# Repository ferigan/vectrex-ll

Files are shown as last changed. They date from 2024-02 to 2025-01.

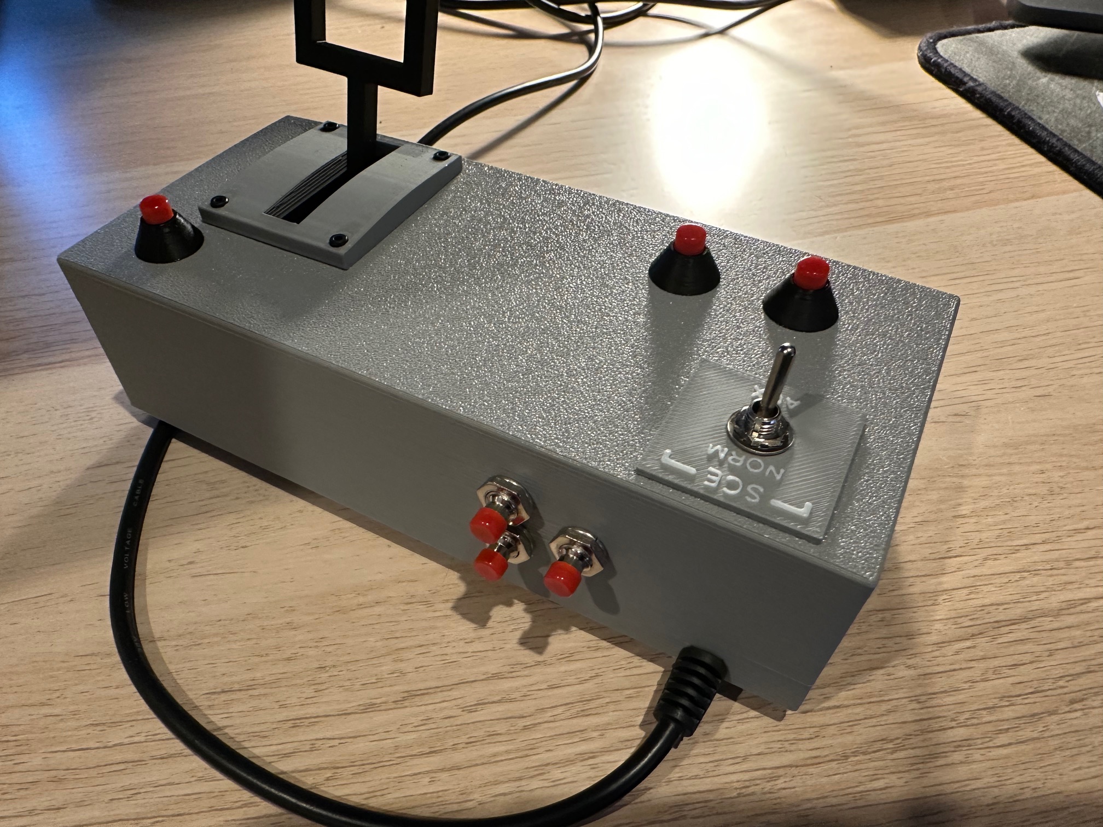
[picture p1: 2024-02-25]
Vectrex_LL_image2.jpg

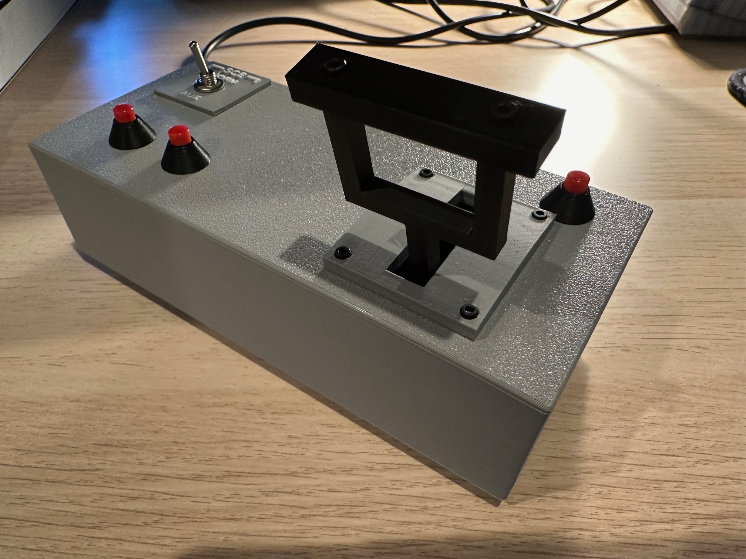
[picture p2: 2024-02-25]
Vectrex_LL_image1.jpg

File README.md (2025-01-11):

# vectrex-ll
Vectrex Lunar Lander controller
Vectrex_LL_image1

This project contains the designs and documentation for a prototype Vectrex Controller intended to be used for games such as Lunar Lander and Moon Lander

I have continued to develop the prototype into a final product, which can be built to order by emailing vectrex@retrocontrollers.com and requesting more information.

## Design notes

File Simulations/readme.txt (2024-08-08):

The simulation files provide here are designed to be used with https://www.falstad.com/circuit/circuitjs.html

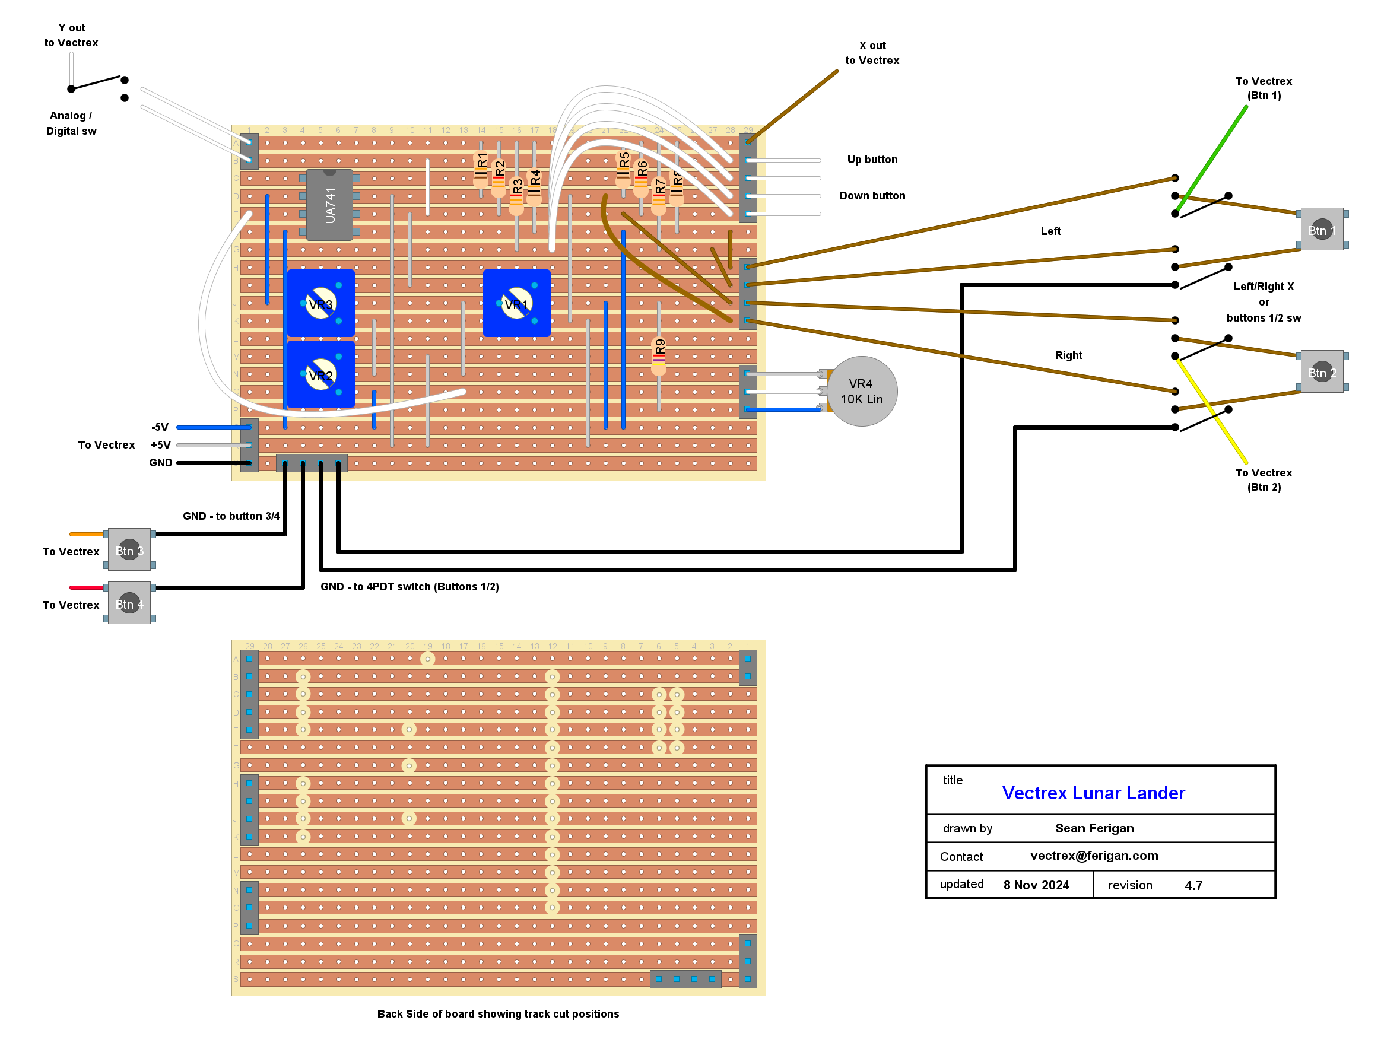
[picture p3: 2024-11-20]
Electronics/vectrex-ll-circuit-v4b.png

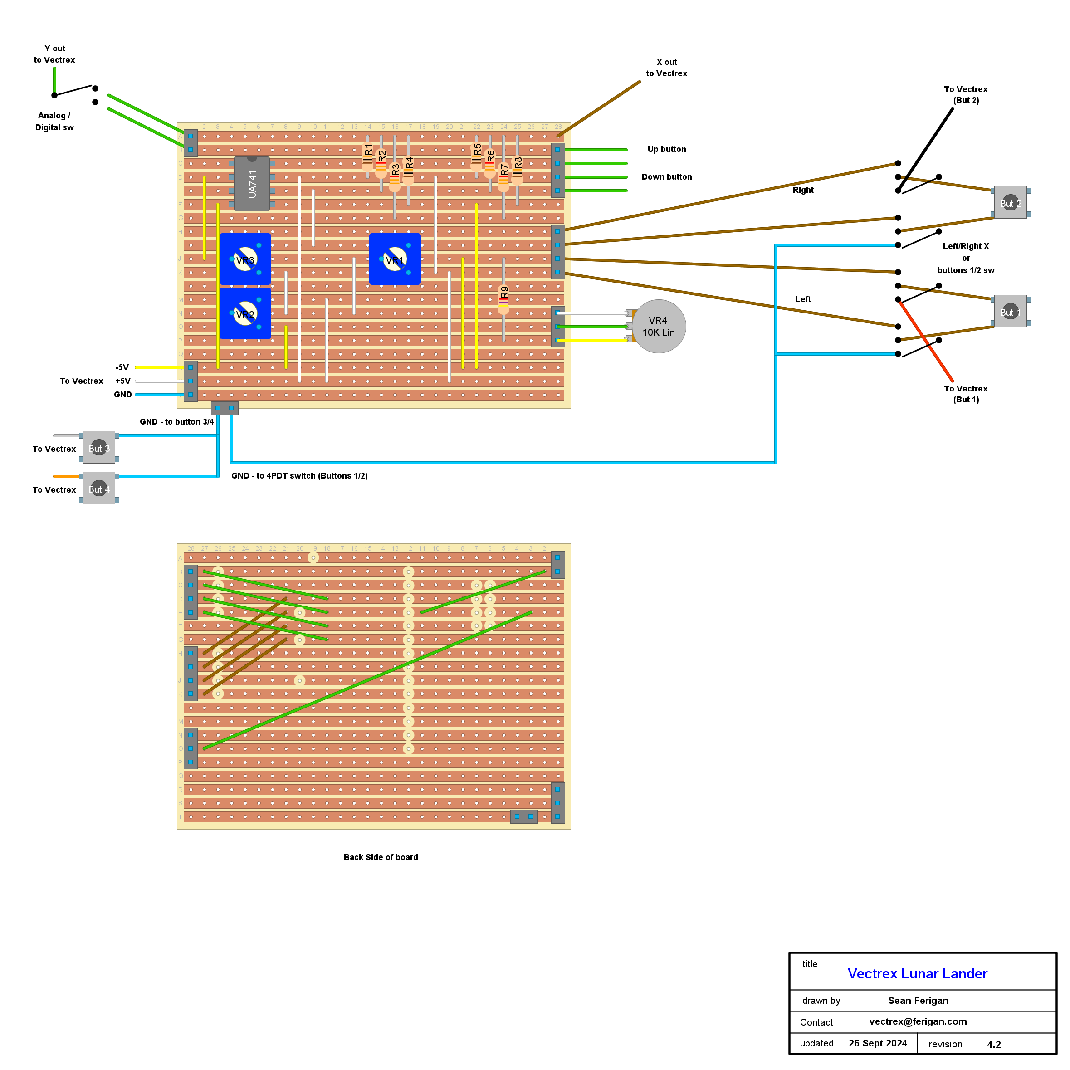
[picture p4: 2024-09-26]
vectrex-ll-circuit-v4.png

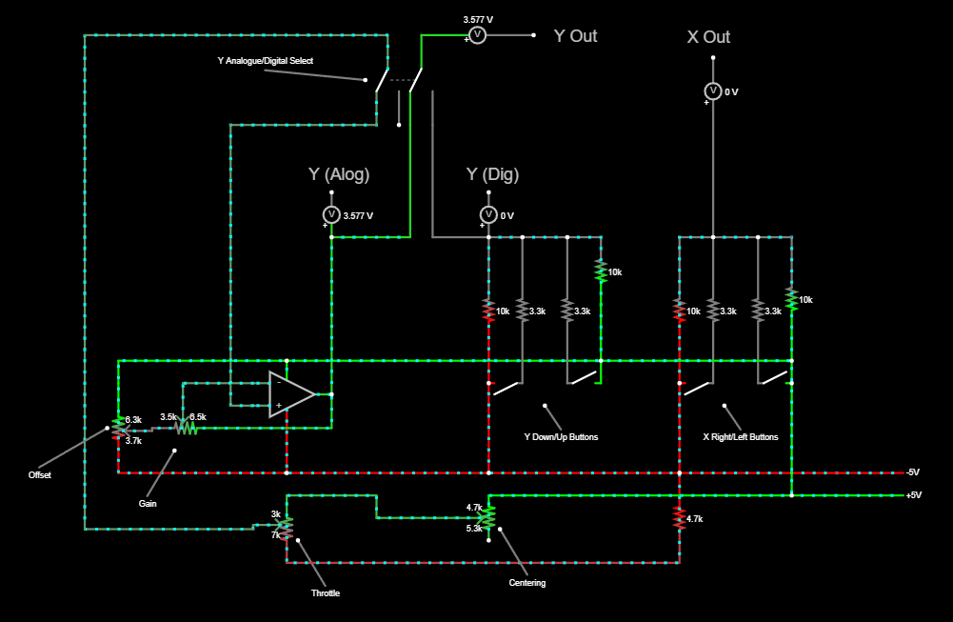
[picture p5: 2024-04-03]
Simulations/Vectrex-LL V2.6.1-sim.png

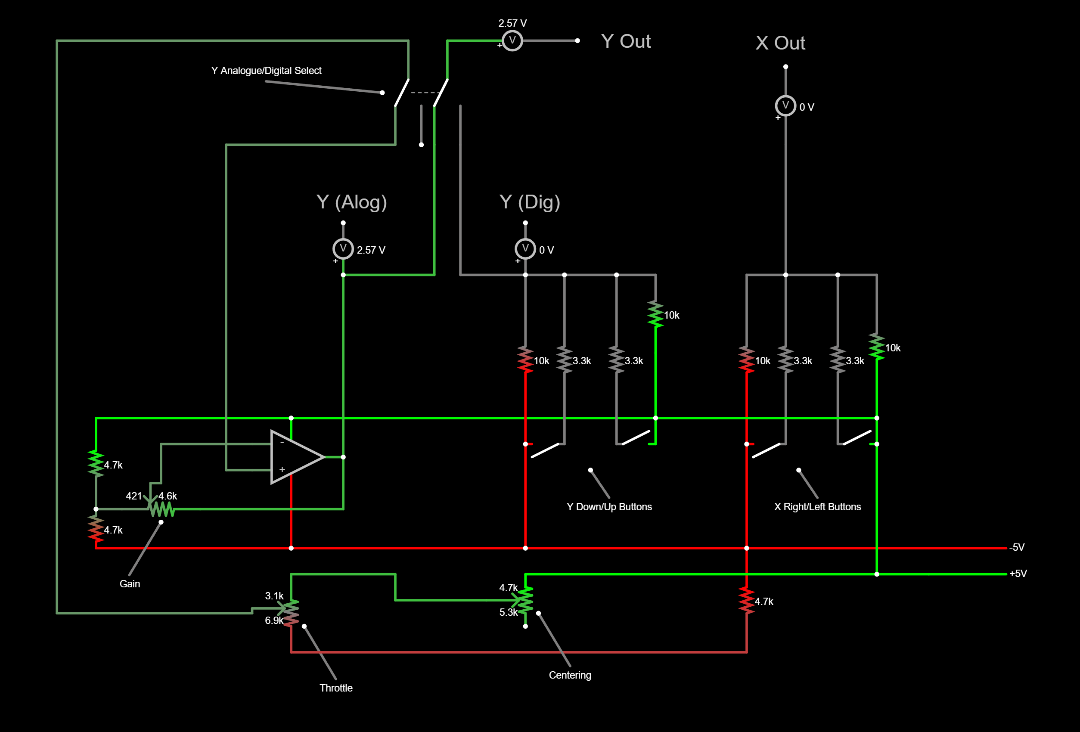
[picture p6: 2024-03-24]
Simulations/Vectrex-LL V2.6-sim.png

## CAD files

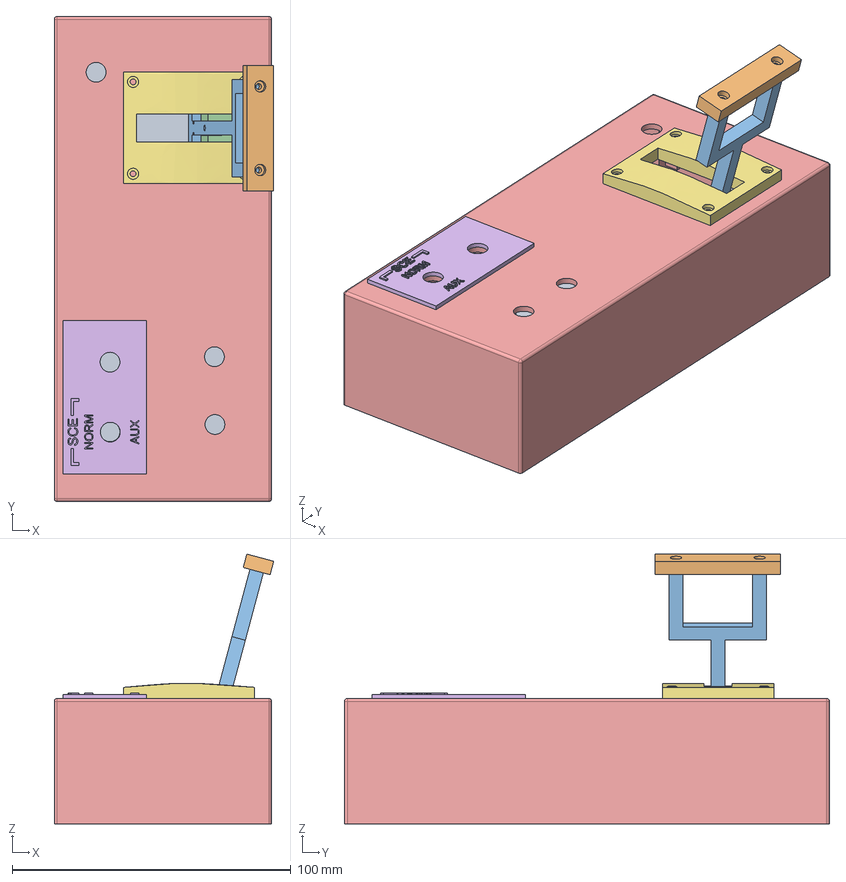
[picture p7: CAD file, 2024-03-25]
3D Print Models/Vectrex Lunar Lander Controller v47.step
78.7 x 174.0 x 96.8 mm
Frame
Handle
Pivot Bar
Bearing Retainer
Top Cover
Switch Plate
Yoke Cover Plate

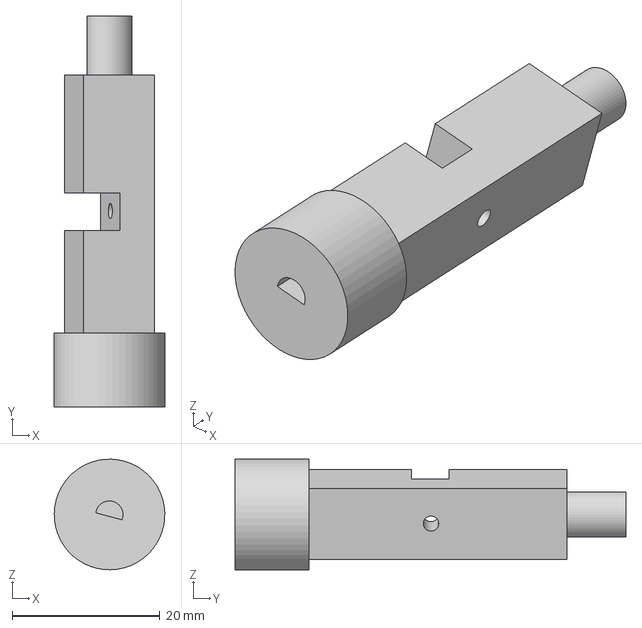
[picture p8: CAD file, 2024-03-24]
3D Print Models/Vectrex Lunar Lander Controller - Joystick Micro Pot v4.step
15.0 x 53.0 x 15.0 mm

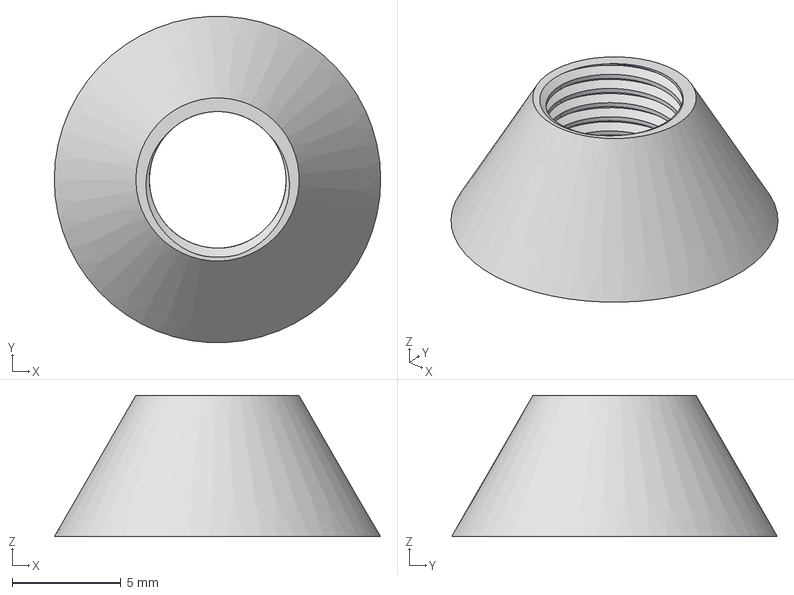
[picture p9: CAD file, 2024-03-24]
3D Print Models/Micro Momentary Button Cone Cover v7.step
15.0 x 15.0 x 6.50 mm

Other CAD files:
3D Print Models/Vectrex Lunar Lander Controller v43.step

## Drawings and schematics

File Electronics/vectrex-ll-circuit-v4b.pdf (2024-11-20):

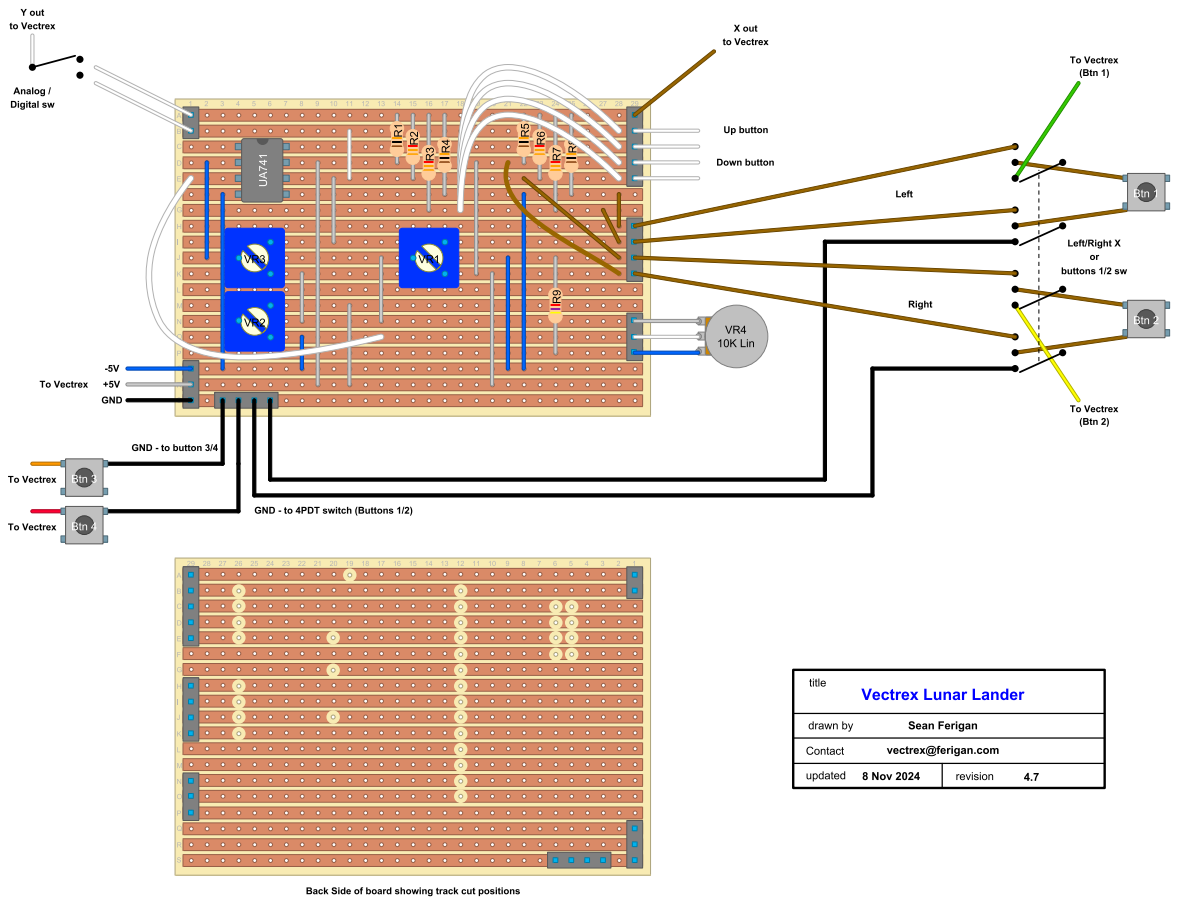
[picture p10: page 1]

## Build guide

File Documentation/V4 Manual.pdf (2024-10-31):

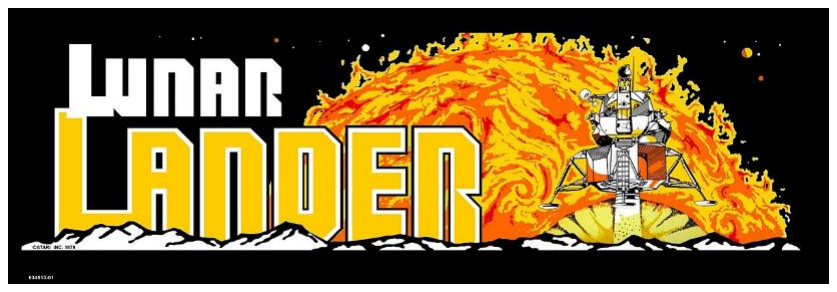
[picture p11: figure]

Vectrex Lunar Lander Controller V4 - Sean Ferigan (vectrex@ferigan.com)

# Vectrex Controller

Vectrex Lunar Lander Controller V4 - Sean Ferigan (vectrex@ferigan.com)

Lunar Lander is a single-player arcade game developed by Atari and released in 1979. The player controls a lunar landing module and attempts to land safely on the Moon. The player can rotate the module and fire a thruster, burning fuel in the process, attempting to gently land on marked areas with varying score multipliers based on difficulty. The scenario resets after every successful landing or crash, with new terrain, until no fuel remains. It’s really a simulation that, on the surface, looks simplistic. It’s attraction (to me anyway) is to see how many landings you can successfully make before exhausting your meagre fuel allowance.
It was the first fully electronic arcade game that I played. Prior to this all the arcade machines I’d played on were electro-mechanical, so this was a whole new experience. Roll forward to now, where I found that you could play Lunar Lander on the Vectrex in all its vector glory! I yearned for a controller like the one I loved from the arcades and decided to make it a reality!
I hope you enjoy it as much as I do!
Sean

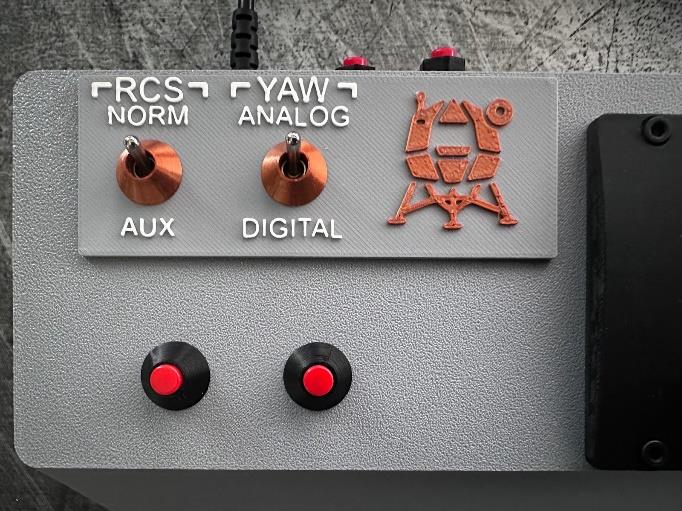
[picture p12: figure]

Vectrex Lunar Lander Controller V4 - Sean Ferigan (vectrex@ferigan.com)

The Vectrex Lunar Lander controller aims to recreate some of the feeling of playing Lunar Lander in the arcades. It replicates the throttle of the original as well as the button layout. The games that this controller has been tested with all require it to be plugged into port 1 of the Vectrex unit. It has been tested with Lunar Lander on both PiTrex and VecFever (for those fortunate enough to own one) as well as with the 3rd party game Moon Lander. There may be other games with a similar control scheme that I’m not aware of at the time of writing this.
These games are supported through switchable control mapping using the RCS and YAW switches located on the top of the controller.

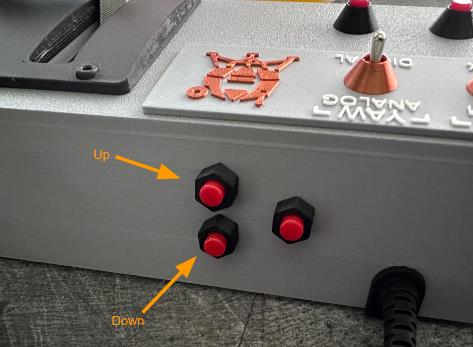
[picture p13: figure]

Vectrex Lunar Lander Controller V4 - Sean Ferigan (vectrex@ferigan.com)

RCS - Reaction Control System
In NORM mode, the throttle lever is used to control ship thrust. It replicates the Vectrex analog joystick centre to fully “up”.
In AUX mode, there are two buttons on the back face of the controller for up and down. This mode is used for navigating game menus etc.

YAW
In ANALOG mode the left and right buttons replicate joystick left and right.
In DIGITAL mode the left and right buttons replicate button 1 and 2.

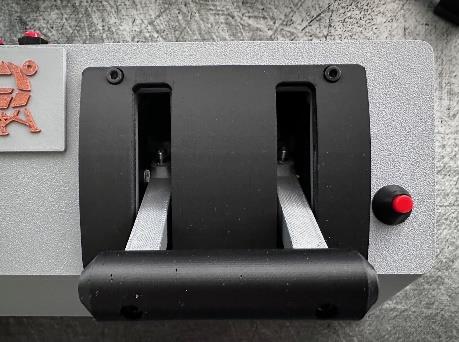
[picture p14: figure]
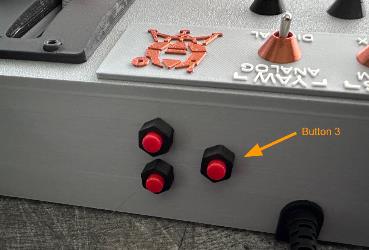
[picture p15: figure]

Vectrex Lunar Lander Controller V4 - Sean Ferigan (vectrex@ferigan.com)

Button 4 is to the right of the throttle. In the VecFever version of Lunar Lander this triggers the abort feature, just like in the original arcade version.

Finally, if needed, Button 3 can be found on the back of the controller:

Vectrex Lunar Lander Controller V4 - Sean Ferigan (vectrex@ferigan.com)

Important Note
This controller is hobbyist designed and hand assembled. Therefore, consider it a prototype with no warranty and likely some design flaws. Whilst effort has been made to ensure that it will provide enjoyment over a long period of time there are no guarantees!

Lastly, if you have any ideas for improvements to this controller or other controller designs I’d love to hear from you. Just drop me an email – vectrex@ferigan.com

Vectrex Lunar Lander Controller V4 - Sean Ferigan (vectrex@ferigan.com)

Control Switch Configurations Table

RCS | YAW | Controls
Norm | Analog | Throttle Lever – Thrust (Joystick centre to full up) Left/Right buttons – Joystick left/right
Norm | Digital | Throttle Lever – Thrust (Joystick centre to full up) Left/Right buttons – Buttons 1/2
Aux | Analog | Up/down buttons on rear of controller Left/Right buttons – Joystick left/right
Aux | Digital | Up/down buttons on rear of controller Left/Right buttons – Buttons 1/2

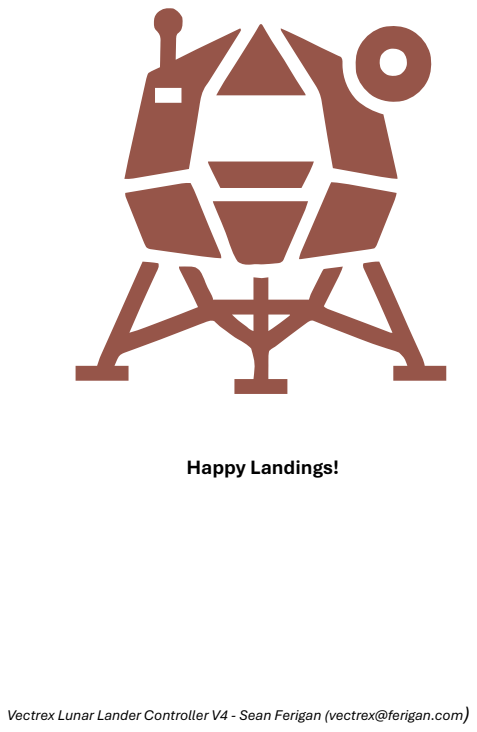
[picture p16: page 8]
Happy Landings!

Vectrex Lunar Lander Controller V4 - Sean Ferigan (vectrex@ferigan.com)

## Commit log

2024-02-18 Step file containing controller for 3D printing
    [Vectrex Lunar Lander Controller v43.step]
2024-02-18 Controller board schematic
2024-02-25 Add files via upload
    Pivot bar designed for small 50 degree 10k potentiometer taken from a joystick
    [Vectrex Lunar Lander Controller - Joystick Pot v4.step]
2024-02-27 Add files via upload
    Atari inspired cone-shaped threaded cover for mini momentary push buttons (https://www.amazon.co.uk/gp/product/B08P482QH3)
    [Micro Momentary Button Cone Cover v7.step]
2024-03-06 Add files via upload
    Latest circuit design and BOM
2024-03-12 Falstad circuit simulator LL control board
    Use with https://www.falstad.com/circuit/circuitjs.html
2024-03-17 Control board with OpAmp on Y axis
    This version of the controller board has an OpAmp on the Y axis to give total control over the rotation required to go from zero to full throttle (Y centre to full up).
2024-03-24 Add files via upload
    V2 board simulation to use in https://www.falstad.com/circuit/circuitjs.html
2024-03-24 Add files via upload
    Replaced "offset" potentiometer with a pair of fixed resistors
2024-03-25 Various
    Removed some old files, renamed some for clarity and added latest 3D model
    [Vectrex Lunar Lander Controller - Joystick Micro Pot v4.step, Vectrex Lunar Lander Controller v47.step]
2024-08-08 removing deprecated circuit design/bom
2024-09-22 Update vectrex-ll-circuit-v4.png
    Fixed some labels
2024-09-26 Update vectrex-ll-circuit-v4.png
    Fixed an error
2024-10-21 Wiring improvements
